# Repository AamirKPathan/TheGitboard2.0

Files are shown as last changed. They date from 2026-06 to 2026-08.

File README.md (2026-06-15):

# GitBoard 2.0





## Project Description
GitBoard 2.0 is an **8‑key Git‑focused macropad** powered by the **Seeeduino XIAO RP2040**.  
It automates common Git commands using **CircuitPython** or **QMK**, making version control faster and more intuitive.

The board uses a **2×4 layout**, **direct‑wired switches**, and a custom PCB designed in **KiCad**.  
Each key triggers a Git command such as `git status`, `git add .`, or `git commit -m ""`.

---

# 📸 Required Images

## 1. Macropad Render
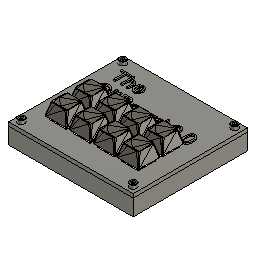
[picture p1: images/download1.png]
Macropad Render


## 2. Schematic Screenshot
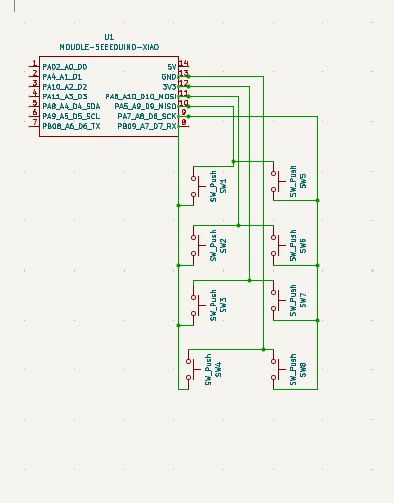
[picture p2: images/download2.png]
Schematic


## 3. PCB Layout Screenshot
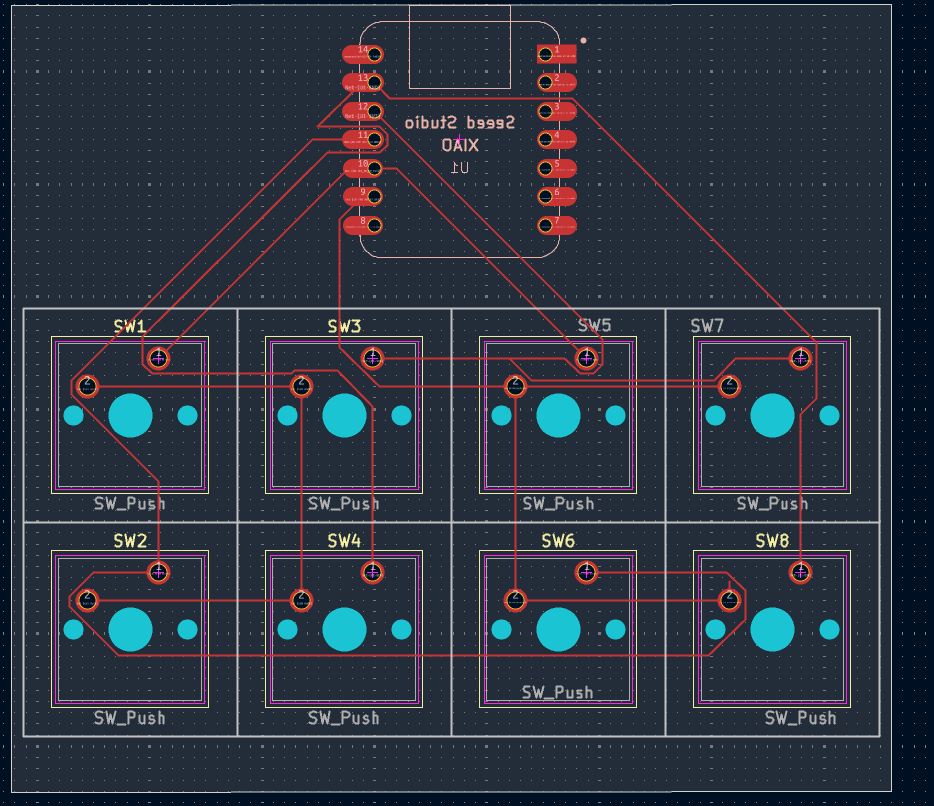
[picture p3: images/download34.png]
PCB Layout


## 4. Case / 3D View Screenshot
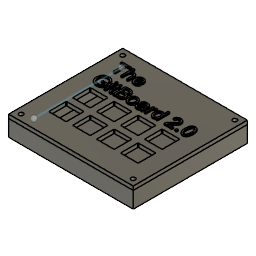
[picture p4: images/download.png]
3D Case


---

## 🛠️ Hardware
- Microcontroller: Seeeduino XIAO (RP2040)
- Switches: 8 × momentary push buttons
- Layout: 2 rows × 4 columns
- Wiring: Direct pins (D0–D7)
- Connection: USB‑C
- Power: 5 V from USB
- Design Software: KiCad 7.x

---

## 💻 CircuitPython Firmware Example

```python
import board, digitalio, usb_hid
from adafruit_hid.keyboard import Keyboard

kbd = Keyboard(usb_hid.devices)

pins = [board.D0, board.D1, board.D2, board.D3, board.D4, board.D5, board.D6, board.D7]
commands = [
    "git status\n",
    "git add .\n",
    "git commit -m \"\"\n",
    "git push\n",
    "git pull\n",
    "git checkout -b newbranch\n",
    "git merge main\n",
    "git log --oneline\n"
]

switches = [digitalio.DigitalInOut(pin) for pin in pins]
for sw in switches:
    sw.direction = digitalio.Direction.INPUT
    sw.pull = digitalio.Pull.UP

while True:
    for i, sw in enumerate(switches):
        if not sw.value:
            kbd.send_string(commands[i])
```

---

## ⚙️ QMK Firmware
The QMK firmware for this board is located in the `firmware/` folder.

### Matrix Layout
Direct‑wired 2×4 matrix:

```
Row 0 → D0, D1, D2, D3  
Row 1 → D4, D5, D6, D7
```

---

## 📦 Bill of Materials (BOM)

| Item | Quantity | Description | Footprint |
|---|---|---|---|
| Seeeduino XIAO | 1 | Microcontroller | MODULE‑SEEEDUINO‑XIAO |
| Tactile Switch | 8 | Momentary push button | SW_Push |
| Custom PCB | 1 | Designed in KiCad | — |
| USB‑C Cable | 1 | Power + data | — |
| Solder | — | Assembly | — |
| Keycaps | 8 | For labeling | — |
| Case | 1 | 3D printed enclosure | — |
| Screws | 4 | M3×16 | — |

---

## 🧰 License
MIT License

---

## 🚀 Future Ideas
- RGB LEDs  
- OLED display  
- QMK layers  
- Custom keycaps  
- Encoder support  
- Hotswap sockets

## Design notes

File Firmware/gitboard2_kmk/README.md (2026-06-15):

# GitBoard 2.0 — KMK Firmware Installation Guide

This guide explains how to install and run the KMK firmware for the GitBoard 2.0, an 8‑key macro pad designed for Git workflow shortcuts. KMK runs directly on the RP2040 — no compiling, no QMK setup, and no toolchains required.

---

## Folder Structure

Your firmware folder should look like this:

gitboard2_kmk/
├── kmk/
├── code.py
└── boot.py   (optional)

---

## Requirements

You will need:

- An RP2040 board (such as a Raspberry Pi Pico or compatible)
- A USB cable
- The firmware folder shown above

---

## Flashing KMK to the RP2040

1. Hold the **BOOTSEL** button on the RP2040.
2. While holding BOOTSEL, plug the board into your computer.
3. A USB drive named **RPI-RP2** will appear.
4. Copy the following items onto the RPI-RP2 drive:

   - The entire **kmk/** folder
   - **code.py**
   - **boot.py** (optional)

5. Eject the RPI-RP2 drive.
6. Unplug and replug the RP2040 normally.

The board will reboot and run KMK automatically.

---

## Testing the GitBoard

1. Open a text editor or terminal.
2. Press each key on the GitBoard.
3. You should see the Git commands appear instantly.

Examples:
- `git add .`
- `git commit -m ""`
- `git push`
- `git pull`
- `git status`
- `git log`
- `git checkout -b `
- `git clone `

---

## Updating the Firmware

To update your code later:

1. Plug the RP2040 in normally.
2. A drive named **CIRCUITPY** will appear.
3. Replace **code.py** with your updated version.
4. The board reloads automatically.

If CIRCUITPY does not appear, repeat the BOOTSEL flashing steps.

---

## Troubleshooting

**Board does not show up as RPI-RP2**
- Hold BOOTSEL before plugging in
- Try a different USB cable (some are charge‑only)
- Try a different USB port

**Board shows CIRCUITPY but nothing happens**
- Check for syntax errors in code.py
- Delete any file named `boot_out.txt` and reboot

---

## License

This firmware is for personal use with the GitBoard 2.0.

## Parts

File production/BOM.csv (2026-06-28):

Item | Quantity | Description | Footprint | Estimated Cost (CAD) | Notes
Seeeduino XIAO RP2040 | 1 | Microcontroller module | MODULE-SEEEDUINO-XIAO | 10 | Main MCU
Tactile Switch | 8 | Momentary push button | SW_Push | 6 | Direct-wired keys
Custom PCB | 1 | Main board | PCB | 15 | Manufactured via JLCPCB/PCBWay
Keycaps | 8 | MX-compatible keycaps | N/A | 8 | Optional for labeling
USB-C Cable | 1 | Power + data | N/A | 8 | Connects XIAO to PC
Screws M3x16 | 4 | Case mounting hardware | N/A | 3 | Used for top/bottom plate
3D Printed Case | 1 | Enclosure | N/A | 10 | Printed at school/maker space
Solder | 1 | Assembly consumable | N/A | 5 | Used for soldering switches + XIAO
TOTAL |  | Total estimated project cost |  | 65 | Typical range: $55–$90 CAD

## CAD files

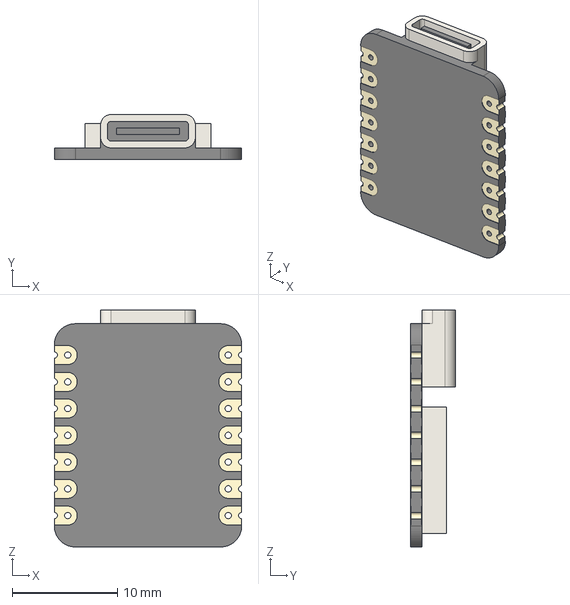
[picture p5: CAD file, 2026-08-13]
Components/Seeeduino Xiao.step
17.8 x 4.27 x 22.5 mm

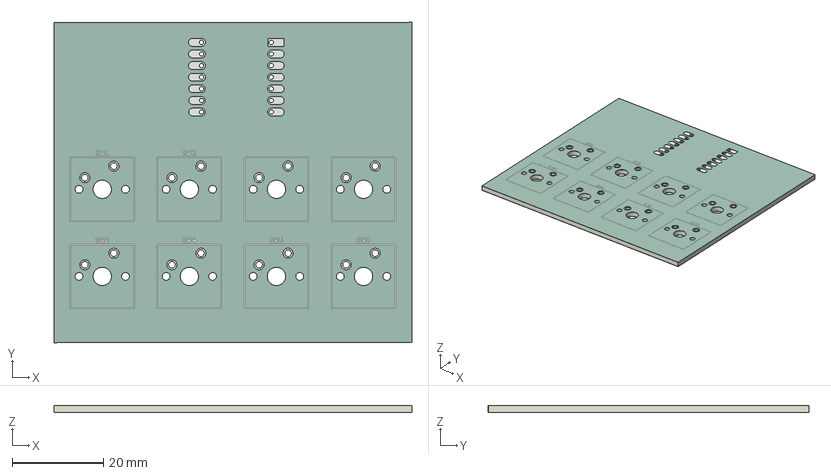
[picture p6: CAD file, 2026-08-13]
PCB/TheGitboard2.0/gitboard.step
78.3 x 70.1 x 1.66 mm
TheGitboard2.0_copper
TheGitboard2.0_pad
TheGitboard2.0_silkscreen x 2
TheGitboard2.0_soldermask x 2
TheGitboard2.0_PCB

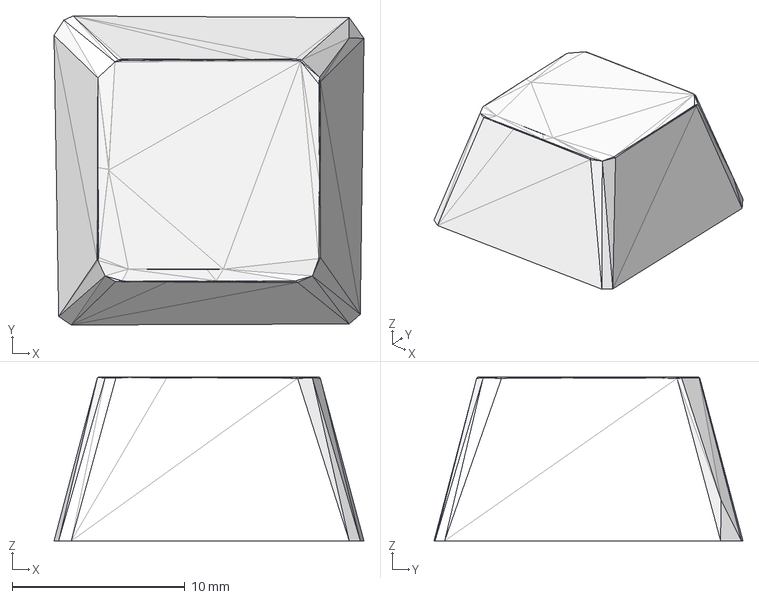
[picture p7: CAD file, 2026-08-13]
Components/Simple-CherryMX-Keycap.step
18.0 x 17.9 x 9.50 mm

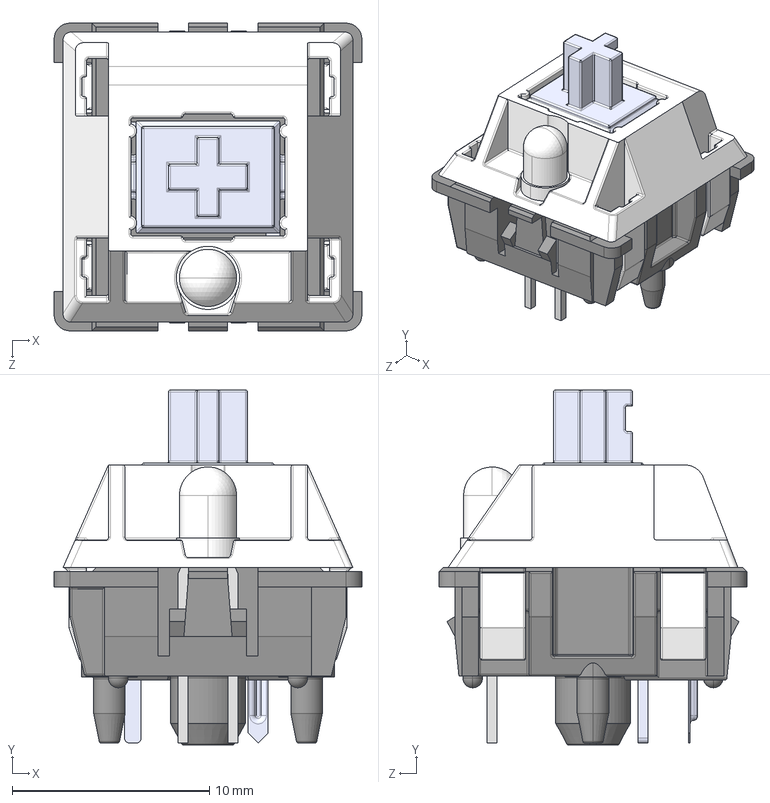
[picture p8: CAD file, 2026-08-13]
Components/Cherry MX.STEP
15.6 x 18.0 x 15.6 mm
Bottom
Pulsador
Top
Pieza5^Cherry MX
Pin1
Pin2
Led 3mm_trans

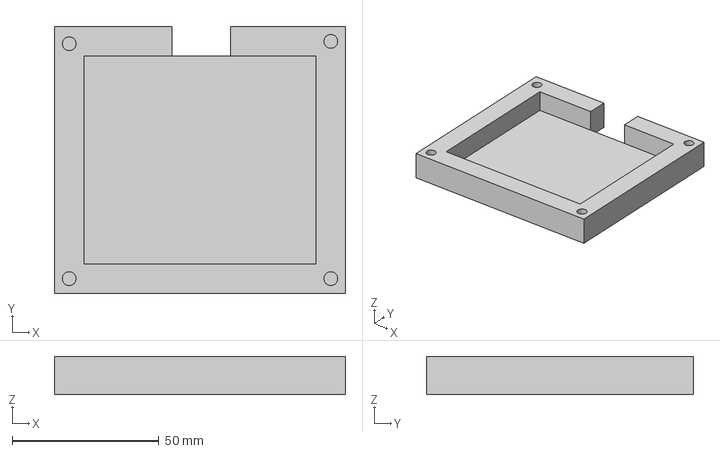
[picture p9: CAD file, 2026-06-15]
Components/Gitboard2.0 Bottom Plate Final.step
99.1 x 90.8 x 13.0 mm

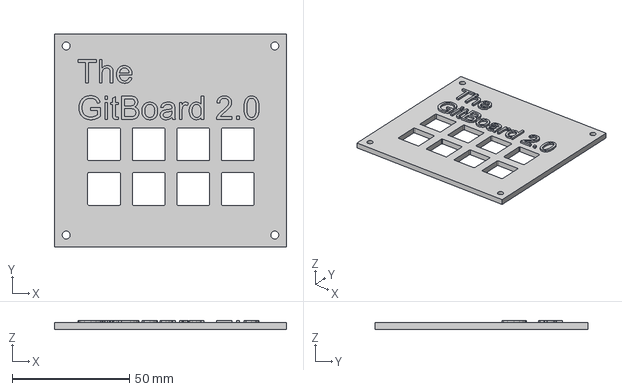
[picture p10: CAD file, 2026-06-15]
Components/Top Plate Gitboard2.0 Final.step
99.1 x 90.8 x 4.00 mm

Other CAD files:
production/gitboard.step
Components/gitboard.step

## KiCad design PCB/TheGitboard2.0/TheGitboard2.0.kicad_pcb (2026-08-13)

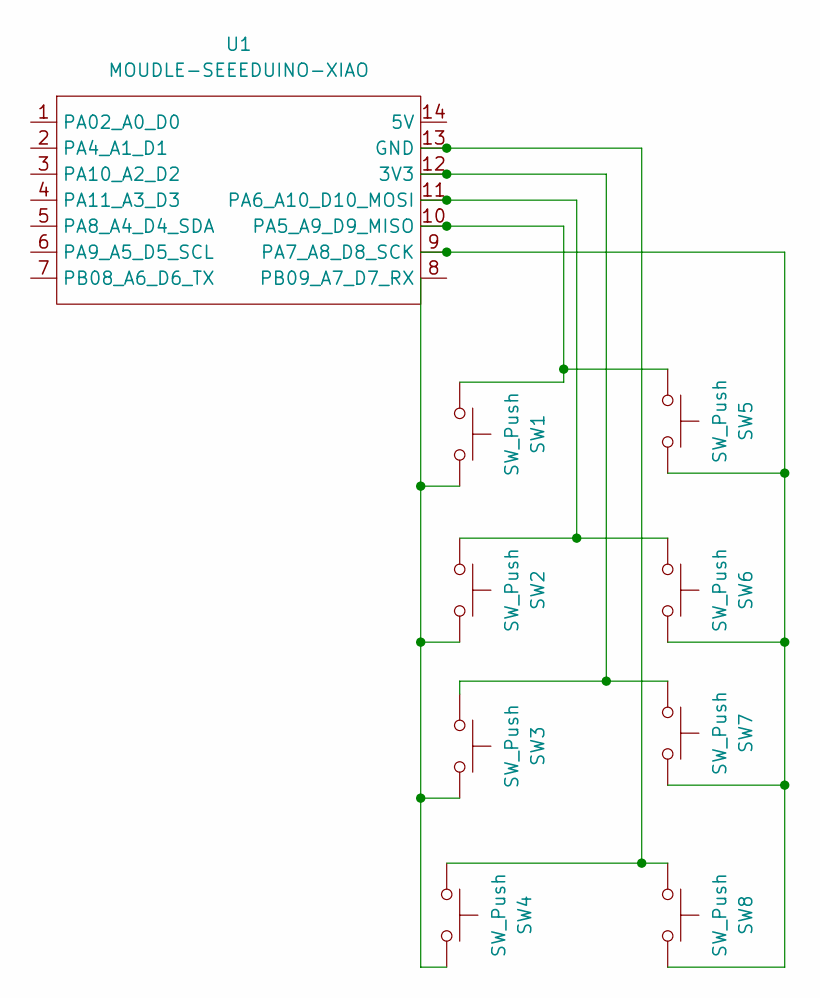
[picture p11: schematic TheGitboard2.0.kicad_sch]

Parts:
SW1, SW2, SW3, SW4, SW5, SW6, SW7, SW8: SW_Push; SW_Cherry_MX_1.00u_PCB
U1: MOUDLE-SEEEDUINO-XIAO; XIAO-Generic-Hybrid-14P-2.54-21X17.8MM

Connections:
unnamed: SW1.2, SW2.2, SW3.2, SW4.2
unnamed: SW3.1, SW7.1, U1.12 (3V3)
unnamed: SW4.1, SW8.1, U1.13 (GND)
unnamed: SW1.1, SW5.1, U1.10 (PA5_A9_D9_MISO)
unnamed: SW2.1, SW6.1, U1.11 (PA6_A10_D10_MOSI)
unnamed: SW5.2, SW6.2, SW7.2, SW8.2, U1.9 (PA7_A8_D8_SCK)

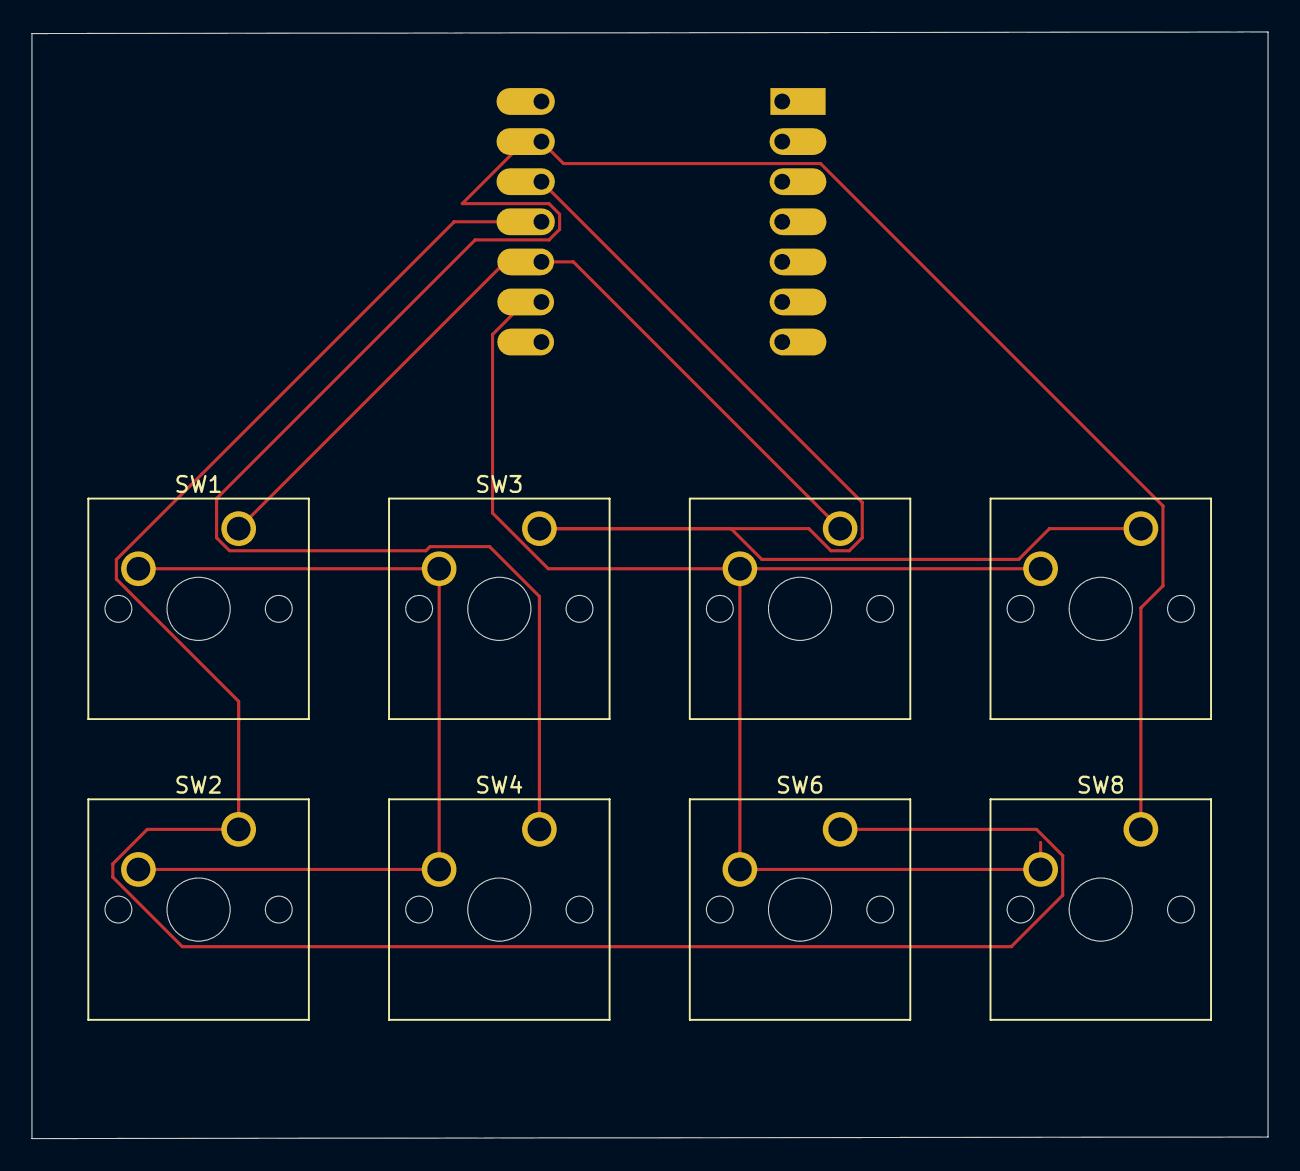
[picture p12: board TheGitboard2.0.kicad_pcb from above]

Board: 2 copper layers, 78.3 x 70.1 mm, 9 parts (1 on the bottom side), 6 nets.

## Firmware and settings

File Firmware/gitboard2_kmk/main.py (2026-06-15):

import board
from kmk.kmk_keyboard import KMKKeyboard
from kmk.scanners import DiodeOrientation
from kmk.scanners.keypad import MatrixScanner
from kmk.keys import KC
from kmk.handlers.sequences import send_string

keyboard = KMKKeyboard()

# -----------------------------
# PIN DEFINITIONS FOR XIAO
# -----------------------------
ROW_PINS = (board.D0, board.D1)
COL_PINS = (board.D2, board.D3, board.D4, board.D5)

# -----------------------------
# MATRIX SETUP (NO DIODES)
# -----------------------------
keyboard.matrix = MatrixScanner(
    row_pins=ROW_PINS,
    col_pins=COL_PINS,
    diode_orientation=DiodeOrientation.NONE,
)

# -----------------------------
# GITHUB MACROS (AUTO-TYPED)
# -----------------------------
GIT_ADD_ALL      = send_string("git add .")
GIT_COMMIT       = send_string('git commit -m ""')
GIT_PUSH         = send_string("git push")
GIT_PULL         = send_string("git pull")
GIT_NEW_BRANCH   = send_string("git checkout -b ")
GIT_SWITCH_BRANCH= send_string("git checkout ")
GIT_STATUS       = send_string("git status")
GIT_LOG          = send_string("git log")

# -----------------------------
# KEYMAP (8 keys)
# Row 0: K0  K1  K2  K3
# Row 1: K4  K5  K6  K7
#
# K0 = git add .
# K1 = git commit -m ""
# K2 = git push
# K3 = git pull
#
# K4 = git status
# K5 = git log
# K6 = git checkout -b (new branch)
# K7 = git checkout (switch branch)
# -----------------------------
keyboard.keymap = [
    [
        GIT_ADD_ALL,        # K0
        GIT_COMMIT,         # K1
        GIT_PUSH,           # K2
        GIT_PULL,           # K3

        GIT_STATUS,         # K4
        GIT_LOG,            # K5
        GIT_NEW_BRANCH,     # K6
        GIT_SWITCH_BRANCH,  # K7
    ]
]

if __name__ == '__main__':
    keyboard.go()

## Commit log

2026-06-15 Add updated README and project files
    [Gitboard2.0 Bottom Plate Final.step, TheGitboard2.0 Complete CAD.step, TheGitboard2.0.kicad_pcb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]
2026-06-28 Jun 28, 2026, 11:16 AM
    [BOM.csv]
2026-06-28 Jun 28, 2026, 11:18 AM
    [BOM.csv]
2026-06-28 Jun 28, 2026, 11:27 AM
    [BOM.csv]
2026-08-13 Aug 13, 2026, 5:17 PM
    [Cherry MX.STEP, Gitboard2.0 Bottom Plate Final.step, Seeeduino Xiao.step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]
2026-08-13 Aug 13, 2026, 5:22 PM
    [TheGitboard2.0-B_Cu.gbl, TheGitboard2.0-B_Mask.gbs, TheGitboard2.0-B_Paste.gbp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]
2026-08-13 Aug 13, 2026, 5:24 PM
    [TheGitboard2.0-NPTH.drl, TheGitboard2.0-PTH.drl]
2026-08-13 Aug 13, 2026, 5:25 PM
    [TheGitboard2.0-B_Cu.gbl, TheGitboard2.0-B_Mask.gbs, TheGitboard2.0-B_Paste.gbp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]
